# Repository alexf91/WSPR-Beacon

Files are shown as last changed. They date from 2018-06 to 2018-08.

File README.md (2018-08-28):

# WSPR Beacon

## IMPORTANT ##

The firmware in this repository was not tested with the PCB design in the
respository.
It was tested on a prototype board with a 3.3V version of an Arduino Nano and a
Si5351 breakout board.

## Getting started

The firmware is built using CMake and requires an installation of `avr-gcc`.

```
cd firmware
mkdir build
cd build
cmake -DCMAKE_BUILD_TYPE=Release ..
make
make flash
```

The beacon is controlled with the `wsprctrl` tool in the `software` directory.
It is written in Python 3 and requires `pyusb`. It is used to set the location,
callsign, frequency and power of the beacon and starts the transmission.
The beacon keeps these settings in memory, so they only have to be set after
a reset. Saving settings to EEPROM is planned.

```
./wsprctrl --correction 26.5
./wsprctrl --drive 8
./wsprctrl --lat 48.210033 --lon 16.363449
./wsprctrl --frequency 7040150
./wsprctrl --call OE5TKM
./wsprctrl --wspr
```

It's also possible to combine multiple options.

## Prototype

* Atmega328 with V-USB for control
* Si5351 with 3 clock outputs (one output per band)
* 40/30/20 meters
* Powered and controlled via USB

### Filter Design

Filter values are taken from [here](https://dk4sx.darc.de/txtp.htm).

## Libraries

* V-USB: http://vusb.wikidot.com/
* Si5351: https://github.com/etherkit/si5351-avr-tiny-minimal/
* I2C: https://github.com/g4lvanix/I2C-master-lib
* UART: http://homepage.hispeed.ch/peterfleury/index.html

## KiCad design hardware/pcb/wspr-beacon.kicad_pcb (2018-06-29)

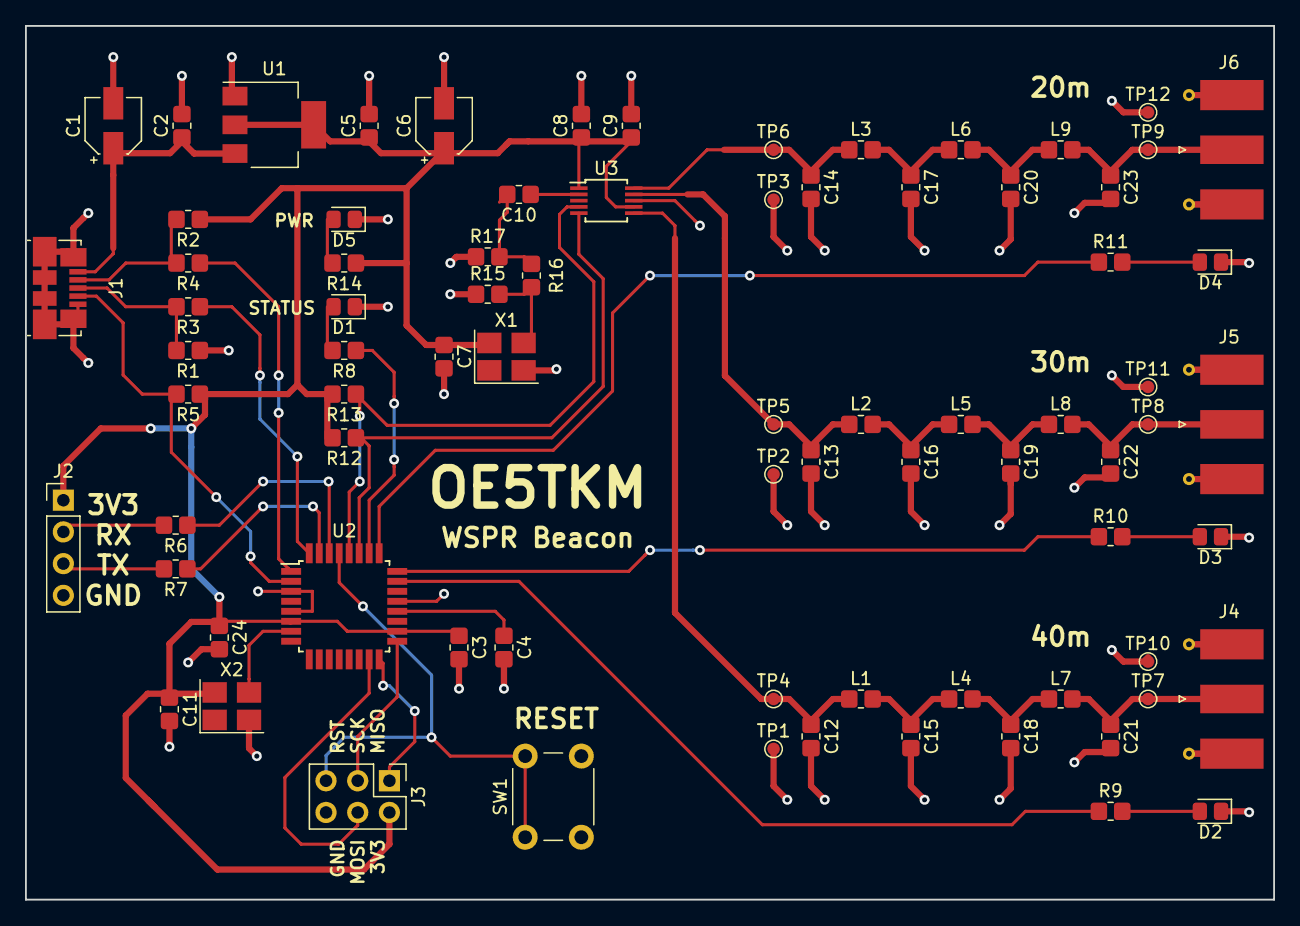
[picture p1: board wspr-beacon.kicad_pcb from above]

Board: 2 copper layers, 100.0 x 70.0 mm, 79 parts (0 on the bottom side), 44 nets.

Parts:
C1, C6: 4u7; CP_Elec_4x4.5
C2, C3, C4, C5, C7, C8, C9, C10, C11, C24: 100n; C_0805_2012Metric_Pad1.33x1.40mm_HandSolder
C12, C21: 430p; C_0805_2012Metric_Pad1.33x1.40mm_HandSolder
C13, C22: 300p; C_0805_2012Metric_Pad1.33x1.40mm_HandSolder
C14, C23: 220p; C_0805_2012Metric_Pad1.33x1.40mm_HandSolder
C15, C18: 820p; C_0805_2012Metric_Pad1.33x1.40mm_HandSolder
C16, C19: 560p; C_0805_2012Metric_Pad1.33x1.40mm_HandSolder
C17, C20: 390p; C_0805_2012Metric_Pad1.33x1.40mm_HandSolder
D1, D2, D3, D4, D5: LED; LED_0805_2012Metric_Pad1.15x1.40mm_HandSolder
J1: USB_OTG; USB_Micro-B_Molex_47346-0001
J2: Conn_01x04; PinHeader_1x04_P2.54mm_Vertical
J3: Conn_02x03_Odd_Even; PinHeader_2x03_P2.54mm_Vertical
J4, J5, J6: Conn_Coaxial; SMA_Molex_73251-1153_EdgeMount_Horizontal
L1, L7: 1u5; L_0805_2012Metric_Pad1.33x1.40mm_HandSolder
L2, L8: 1u; L_0805_2012Metric_Pad1.33x1.40mm_HandSolder
L3, L9: 0.75u; L_0805_2012Metric_Pad1.33x1.40mm_HandSolder
L4: 1u8; L_0805_2012Metric_Pad1.33x1.40mm_HandSolder
L5: 1u2; L_0805_2012Metric_Pad1.33x1.40mm_HandSolder
L6: 0.91u; L_0805_2012Metric_Pad1.33x1.40mm_HandSolder
R1: 1M; R_0805_2012Metric_Pad1.33x1.40mm_HandSolder
R2: 1k5; R_0805_2012Metric_Pad1.33x1.40mm_HandSolder
R3, R4: 68; R_0805_2012Metric_Pad1.33x1.40mm_HandSolder
R5: 100k; R_0805_2012Metric_Pad1.33x1.40mm_HandSolder
R6, R7: 1k; R_0805_2012Metric_Pad1.33x1.40mm_HandSolder
R8, R9, R10, R11, R14, R15, R16, R17: R; R_0805_2012Metric_Pad1.33x1.40mm_HandSolder
R12, R13: 4k7; R_0805_2012Metric_Pad1.33x1.40mm_HandSolder
SW1: SW_Push; SW_PUSH_6mm
TP1, TP2, TP3, TP4, TP5, TP6, TP7, TP8, TP9, TP10, TP11, TP12: TEST; TestPoint_Pad_D1.0mm
U1: AP1117-33; SOT-223-3_TabPin2
U2: ATMEGA328-AU; TQFP-32_7x7mm_P0.8mm
U3: Si5351A; MSOP-10_3x3mm_P0.5mm
X1: ASE-25MHz; Oscillator_SMD_Abracon_ASE-4Pin_3.2x2.5mm_HandSoldering
X2: ASE-16MHz; Oscillator_SMD_Abracon_ASE-4Pin_3.2x2.5mm_HandSoldering

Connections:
+3V3: C3.1, C5.1, C6.1, C7.1, C8.1, C9.1, C11.1, C24.1, J2.1, J3.2, R2.1, R5.1, R12.2, R13.2, R14.1, U1.2, U2.4, U2.6, U2.18, U3.1, U3.7, X1.4, X2.4
/D+: R3.1, U2.32
/D-: R4.1, U2.1
/ID: J1.4, R5.2, U2.2
/LED_20M: R9.1, U2.23
/LED_30M: R10.1, U2.24
/LED_40M: R11.1, U2.25
/LED_ACTIVE: R8.1, U2.26
/MISO: J3.1, U2.16
/MOSI: J3.4, U2.15
/RESET: J3.5, SW1.1, U2.29
/SCK: J3.3, U2.17
/SCL: R13.1, U2.28, U3.4
/SDA: R12.1, U2.27, U3.5
GND: C1.2, C2.2, C3.2, C4.2, C5.2, C6.2, C7.2, C8.2, C9.2, C11.2, C12.2, C13.2, C14.2, C15.2, C16.2, C17.2, C18.2, C19.2, C20.2, C21.2, C22.2, C23.2, C24.2, D1.1, D2.1, D3.1, D4.1, D5.1, J1.5, J1.6, J2.4, J3.6, J4.2, J5.2, J6.2, R1.1, R15.1, R17.1, SW1.2, TP1.1, TP2.1, TP3.1, TP10.1, TP11.1, TP12.1, U1.1, U2.3, U2.5, U2.21, U3.8, X1.2, X2.2
unnamed: C4.1, U2.20
unnamed: C10.1, U3.2
unnamed: C10.2, R16.2, R17.2
unnamed: C12.1, L1.1, TP4.1, U3.6
unnamed: C13.1, L2.1, TP5.1, U3.9
unnamed: C14.1, L3.1, TP6.1, U3.10
unnamed: C15.1, L1.2, L4.1
unnamed: C16.1, L2.2, L5.1
unnamed: C17.1, L3.2, L6.1
unnamed: C18.1, L4.2, L7.1
unnamed: C19.1, L5.2, L8.1
unnamed: C20.1, L6.2, L9.1
unnamed: C21.1, J4.1, L7.2, TP7.1
unnamed: C22.1, J5.1, L8.2, TP8.1
unnamed: C23.1, J6.1, L9.2, TP9.1
unnamed: D1.2, R8.2
unnamed: D2.2, R9.2
unnamed: D3.2, R10.2
unnamed: D4.2, R11.2
unnamed: D5.2, R14.2
unnamed: J1.2, R2.2, R4.2
unnamed: J1.3, R1.2, R3.2
unnamed: J2.2, R6.2
unnamed: J2.3, R7.2
unnamed: R6.1, U2.30
unnamed: R7.1, U2.31
unnamed: R15.2, R16.1, X1.3
unnamed: U2.7, X2.3
VBUS: C1.1, C2.1, J1.1, U1.3

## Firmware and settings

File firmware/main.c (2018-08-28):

/*
 * Copyright 2018 Alexander Fasching
 *
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
 * You should have received a copy of the GNU General Public License
 * along with this program. If not, see <http://www.gnu.org/licenses/>.
 */

#include <stdio.h>
#include <stdbool.h>
#include <avr/io.h>
#include <avr/interrupt.h>
#include <util/delay.h>
#include <util/atomic.h>

#include "uart.h"
#include "usbdrv.h"
#include "beacon.h"
#include "debug.h"


/* USB requests */
enum Request {
    REQ_ENABLE_LED = 0,     /* Enable the LED */
    REQ_DISABLE_LED,        /* Disable the LED */
    REQ_SET_FREQ,           /* Set the frequency of an output */
    REQ_SET_DRIVE,          /* Set drive strenght for an output */
    REQ_SET_CALL,           /* Set the callsign */
    REQ_SET_FREQ_CORR,      /* Set frequency correction value */
    REQ_TRANSMIT_TONE,      /* Transmit a continuous tone */
    REQ_TRANSMIT_WSPR,      /* Start a WSPR transmission */
    REQ_SET_LAT,            /* Set the latitude */
    REQ_SET_LON,            /* Set the longitude */
};


static inline void led_init(void) { DDRB |= (1<<PB5); }
static inline void led_on(void) { PORTB |= (1<<PB5); }
static inline void led_off(void) { PORTB &= ~(1<<PB5); }


/* Structure used as response to requests. */
struct {
    uint16_t value;
    uint16_t status;
} response;


usbMsgLen_t usbFunctionSetup(uchar data[8]) {
    usbRequest_t *rq = (void *) &data[0];

    response.value = 0;
    response.status = 128;

    if (rq->bRequest == REQ_ENABLE_LED) {
        led_on();
        response.status = 0;

    } else if (rq->bRequest == REQ_DISABLE_LED) {
        led_off();
        response.status = 0;

    } else if (rq->bRequest == REQ_SET_FREQ) {
        uint16_t req_index = rq->wIndex.word;
        uint16_t req_value = rq->wValue.word;

        uint8_t output = req_index >> 12;
        uint32_t freq = (((uint32_t)req_index << 16) | req_value) & 0x0FFFFFFF;

        response.status = beacon_set_freq(output, freq);

    } else if (rq->bRequest == REQ_SET_DRIVE) {
        uint16_t output = rq->wIndex.word;
        uint16_t drive = rq->wValue.word;

        response.status = beacon_set_drive_strength(output, drive);

    } else if (rq->bRequest == REQ_SET_CALL) {
        uint16_t index = rq->wIndex.word;
        uint16_t value = rq->wValue.word;

        response.status = beacon_set_callsign(index, value);

    } else if (rq->bRequest == REQ_SET_FREQ_CORR) {
        uint16_t index = rq->wIndex.word;
        uint16_t value = rq->wValue.word;
        int32_t pptm = ((uint32_t)index << 16) | value;

        response.status = beacon_set_correction(pptm);

    } else if (rq->bRequest == REQ_TRANSMIT_TONE) {
        uint16_t out = rq->wIndex.word;
        uint16_t msecs = rq->wValue.word;

        response.status = beacon_transmit_tone(out, msecs);

    } else if (rq->bRequest == REQ_TRANSMIT_WSPR) {
        uint16_t out = rq->wIndex.word;
        response.status = beacon_transmit_wspr(out);

    } else if (rq->bRequest == REQ_SET_LON) {
        uint16_t req_index = rq->wIndex.word;
        uint16_t req_value = rq->wValue.word;

        uint32_t lon = ((uint32_t)req_index << 16) | req_value;

        response.status = beacon_set_longitude(lon);

    } else if (rq->bRequest == REQ_SET_LAT) {
        uint16_t req_index = rq->wIndex.word;
        uint16_t req_value = rq->wValue.word;

        uint32_t lat = ((uint32_t)req_index << 16) | req_value;

        response.status = beacon_set_latitude(lat);
    }

    usbMsgPtr = (void *) &response;
    return sizeof(response);
}


/**
 * Wrapper for stdout redirection.
 */
static int uart_putchar(char c, FILE *stream) {
    uart_putc(c);
    return 0;
}


int main(int argc, char **argv) {
    led_init();

    /* Initialize UART and redirect stdout */
    uart_init(UART_BAUD_SELECT(115200, F_CPU));
    static FILE mystdout = FDEV_SETUP_STREAM(uart_putchar, NULL, _FDEV_SETUP_WRITE);
    stdout = &mystdout;

    /* Initialize the beacon. This initializes I2C, Timer 0 and the Si5351. */
    if (beacon_init()) {
        debug("Beacon initialization failed\n");
        while (1);
    }

    /* Initialize the USB driver and force enumeration. */
    usbInit();
    usbDeviceDisconnect();
    _delay_ms(250);
    usbDeviceConnect();

    sei();

    debug("WSPR Beacon by OE5TKM\n");

    while (1) {
        usbPoll();
        beacon_poll();
    }
    return 0;
}

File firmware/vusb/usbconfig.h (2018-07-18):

/* Name: usbconfig.h
 * Project: V-USB, virtual USB port for Atmel's(r) AVR(r) microcontrollers
 * Author: Christian Starkjohann
 * Creation Date: 2005-04-01
 * Tabsize: 4
 * Copyright: (c) 2005 by OBJECTIVE DEVELOPMENT Software GmbH
 * License: GNU GPL v2 (see License.txt), GNU GPL v3 or proprietary (CommercialLicense.txt)
 */

#ifndef __usbconfig_h_included__
#define __usbconfig_h_included__

/*
General Description:
This file is an example configuration (with inline documentation) for the USB
driver. It configures V-USB for USB D+ connected to Port D bit 2 (which is
also hardware interrupt 0 on many devices) and USB D- to Port D bit 4. You may
wire the lines to any other port, as long as D+ is also wired to INT0 (or any
other hardware interrupt, as long as it is the highest level interrupt, see
section at the end of this file).
+ To create your own usbconfig.h file, copy this file to your project's
+ firmware source directory) and rename it to "usbconfig.h".
+ Then edit it accordingly.
*/

/* ---------------------------- Hardware Config ---------------------------- */

#define USB_CFG_IOPORTNAME      D
/* This is the port where the USB bus is connected. When you configure it to
 * "B", the registers PORTB, PINB and DDRB will be used.
 */
#define USB_CFG_DMINUS_BIT      3
/* This is the bit number in USB_CFG_IOPORT where the USB D- line is connected.
 * This may be any bit in the port.
 */
#define USB_CFG_DPLUS_BIT       2
/* This is the bit number in USB_CFG_IOPORT where the USB D+ line is connected.
 * This may be any bit in the port. Please note that D+ must also be connected
 * to interrupt pin INT0! [You can also use other interrupts, see section
 * "Optional MCU Description" below, or you can connect D- to the interrupt, as
 * it is required if you use the USB_COUNT_SOF feature. If you use D- for the
 * interrupt, the USB interrupt will also be triggered at Start-Of-Frame
 * markers every millisecond.]
 */
#define USB_CFG_CLOCK_KHZ       (F_CPU/1000)
/* Clock rate of the AVR in kHz. Legal values are 12000, 12800, 15000, 16000,
 * 16500, 18000 and 20000. The 12.8 MHz and 16.5 MHz versions of the code
 * require no crystal, they tolerate +/- 1% deviation from the nominal
 * frequency. All other rates require a precision of 2000 ppm and thus a
 * crystal!
 * Since F_CPU should be defined to your actual clock rate anyway, you should
 * not need to modify this setting.
 */
#define USB_CFG_CHECK_CRC       0
/* Define this to 1 if you want that the driver checks integrity of incoming
 * data packets (CRC checks). CRC checks cost quite a bit of code size and are
 * currently only available for 18 MHz crystal clock. You must choose
 * USB_CFG_CLOCK_KHZ = 18000 if you enable this option.
 */

/* ----------------------- Optional Hardware Config ------------------------ */

#define USB_CFG_PULLUP_IOPORTNAME   D
/* If you connect the 1.5k pullup resistor from D- to a port pin instead of
 * V+, you can connect and disconnect the device from firmware by calling
 * the macros usbDeviceConnect() and usbDeviceDisconnect() (see usbdrv.h).
 * This constant defines the port on which the pullup resistor is connected.
 */
#define USB_CFG_PULLUP_BIT          4
/* This constant defines the bit number in USB_CFG_PULLUP_IOPORT (defined
 * above) where the 1.5k pullup resistor is connected. See description
 * above for details.
 */

/* --------------------------- Functional Range ---------------------------- */
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

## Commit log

2018-06-24 Schematic for transmitter mostly finished
    [wspr-beacon.kicad_pcb, wspr-beacon.sch]
2018-06-24 Add schematic for USB interface
    [wspr-beacon.sch]
2018-06-24 Move PCB into separate directory
    [wspr-beacon.kicad_pcb, wspr-beacon.sch]
2018-06-24 Finish schematic and add filter simulation
    [wspr-beacon.sch]
2018-06-24 Add testpoints for GND
    [wspr-beacon.sch]
2018-06-24 Start with layout
    [wspr-beacon.kicad_pcb, wspr-beacon.sch]
2018-06-26 Continue with layout and add pull-ups for I2C
    [wspr-beacon.kicad_pcb, wspr-beacon.sch]
2018-06-26 Add reset button
    [wspr-beacon.kicad_pcb, wspr-beacon.sch]
2018-06-26 First finished version of layout
    [wspr-beacon.kicad_pcb, wspr-beacon.sch]
2018-06-26 Increase via size
    [wspr-beacon.kicad_pcb]
2018-06-27 Update to KiCad 5
    [wspr-beacon.kicad_pcb, wspr-beacon.sch]
2018-06-27 Update Si5351 symbol to KiCad 5.0
2018-06-28 Place 20m output closer to Si5351
    [wspr-beacon.kicad_pcb, wspr-beacon.sch]
2018-06-28 Minor layout and footprint changes
    [wspr-beacon.kicad_pcb, wspr-beacon.sch]
2018-06-28 Add attenuator to clock input of Si5351
    [wspr-beacon.kicad_pcb, wspr-beacon.sch]
2018-06-29 Increase trace width for power and RF lines
    [wspr-beacon.kicad_pcb]
2018-07-18 Control LED over USB
2018-08-21 Add Si5253 and I2C drivers
2018-08-21 Add WSPR encoder
2018-08-21 Set drive strength to 8mA
2020-05-26 Optimize convolutional encoder by using Galois-type shift-registers instead of Fibonacci-type

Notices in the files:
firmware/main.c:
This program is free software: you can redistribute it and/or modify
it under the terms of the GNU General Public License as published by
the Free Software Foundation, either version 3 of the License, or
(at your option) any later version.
